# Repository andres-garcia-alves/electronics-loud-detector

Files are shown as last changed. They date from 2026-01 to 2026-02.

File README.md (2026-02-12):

# Loud Detector

A loud detector based on ATtiny85.  
Sensitivity threshold and buzzer volume can be configured through trimmers.  
Schematics diagram + PCB diagram (KiCAD 9) and case 3D model (Blender) are also provided.  

&nbsp;

### Features & Notes:

- Sound detection via peak-to-peak window (robust)
- Sensitivity (threshold) via RV1 ADC
- Volume is 100% analog (RV2 in series with buzzer)
- Buzzer + LED share PB1 (digital ON/OFF)
- Mic power gating via PB0 (high-side PNP typical => logic inverted)
- Power input: 18650 battery

&nbsp;

### List of Materials

- 1 x ATtiny85 IC
- 1 x KY-037 Audio sensor module
- 1 x BJT Transistor BC547
- 1 x BJT Transistor BC557
- 1 x 10k ohms trimmer
- 1 x 500 ohms trimmer
- 2 x LED (yellow + red)
- 1 x Buzzer (pasive)
- 1 x Resistor 470 ohms
- 1 x Resistor 1k ohms
- 1 x Resistor 10k ohms
- 2 x Resistor 2k ohms
- 1 x Resistor 100k ohms
- 1 x Capacitor 100 uF (electrolitic)
- 1 x Capacitor 10 uF
- 1 x Rocker Button (power on/off)
- 1 x MT3608 DC/DC Step-Up Converter Module
- 2 x Bornier connector 2-pins / 2 x JST connector 2-pins
- 2 x Header connector 2-pins
- 1 x 18650 battery
- 1 x 18650 battery holder
- Wires

&nbsp;

### Screenshots

| Breadboard | Assembly |
|---|---|
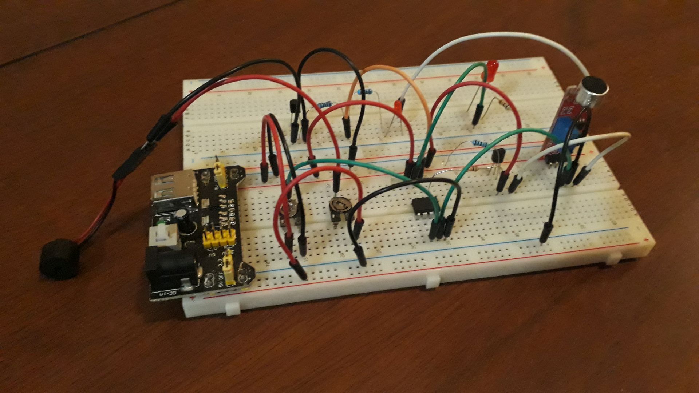
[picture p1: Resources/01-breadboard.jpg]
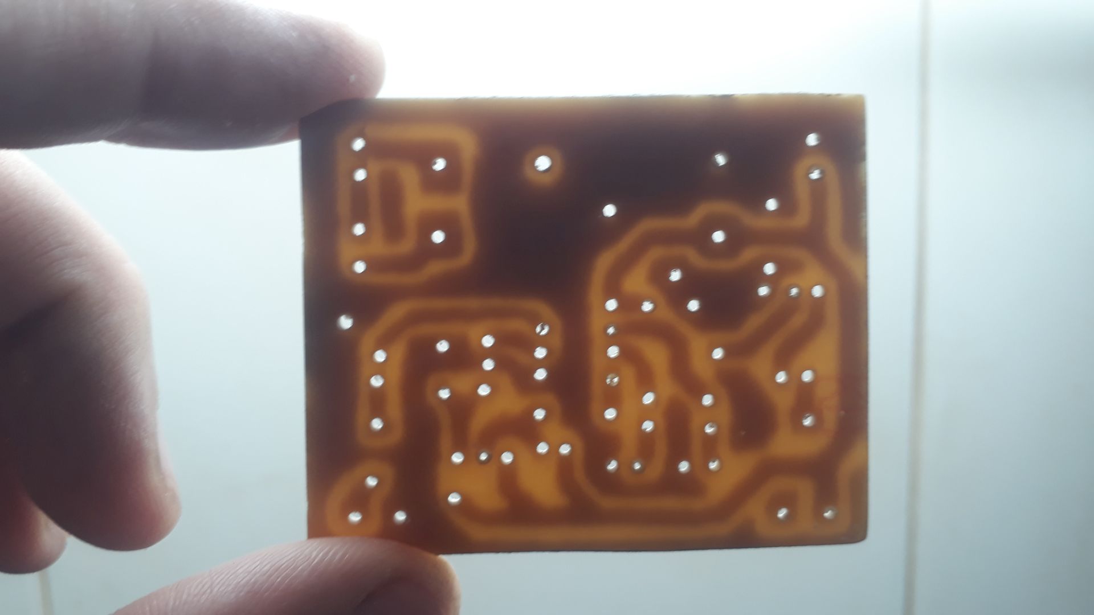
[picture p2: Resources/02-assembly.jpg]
|  |  |

| Schematics Diagram | PCB Layout |
|---|---|
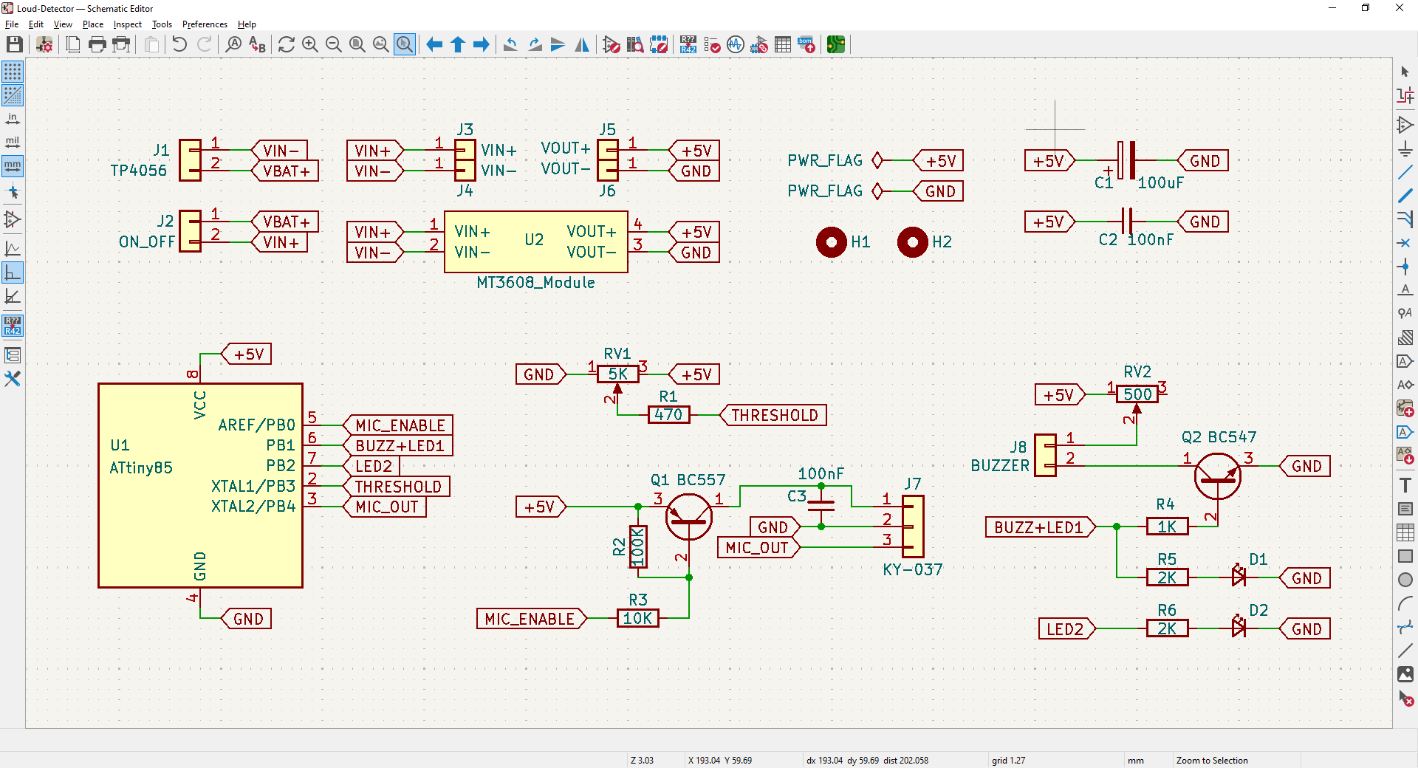
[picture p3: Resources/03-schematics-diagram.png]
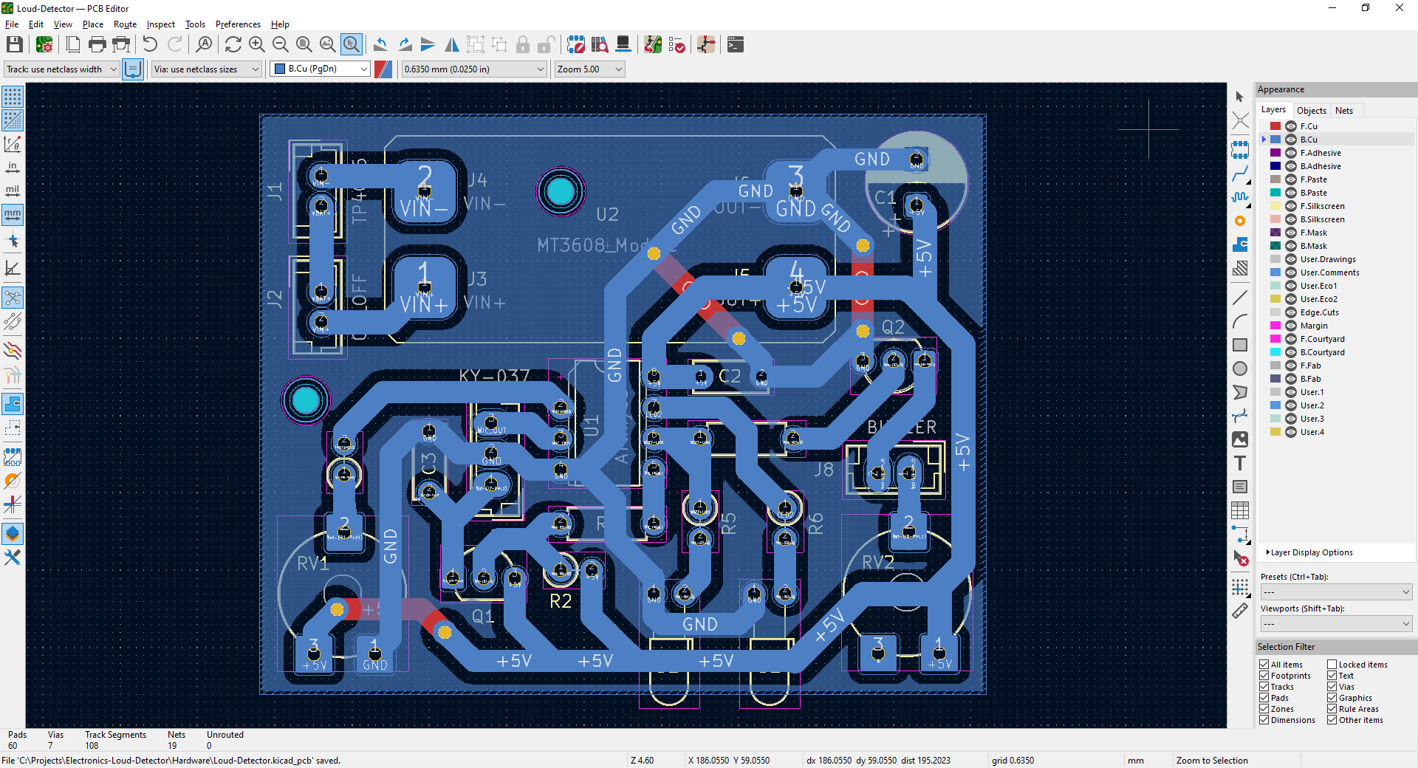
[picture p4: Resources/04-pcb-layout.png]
|  |  |

| PCB Render 3D | PCB Render 3D |
|---|---|
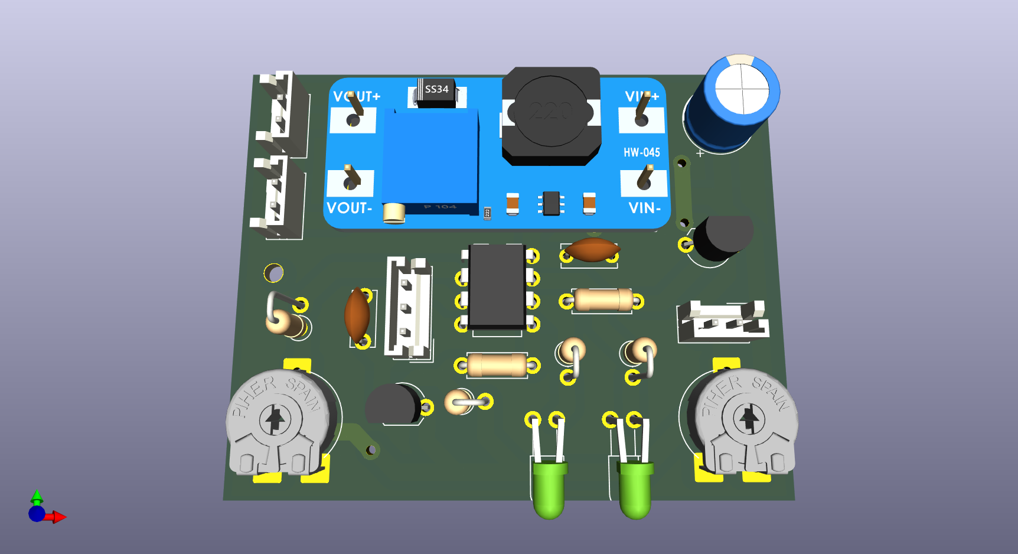
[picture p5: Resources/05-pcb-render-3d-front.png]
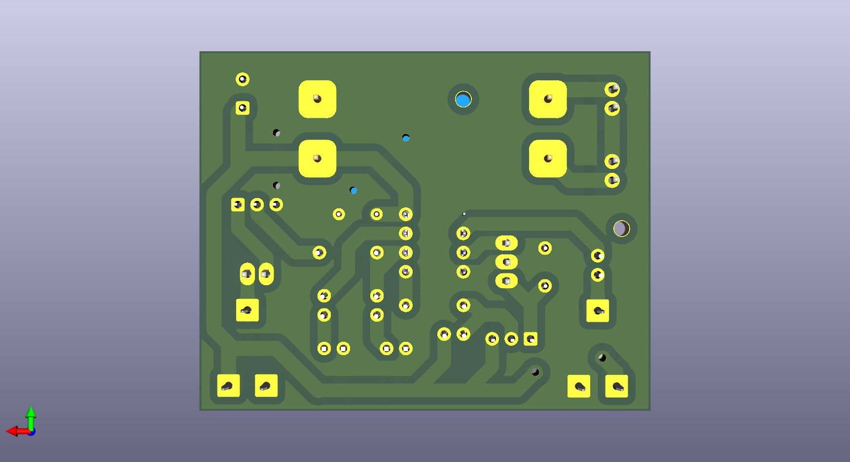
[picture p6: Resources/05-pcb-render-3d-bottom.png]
|  |  |

| Case 3D Model | Project Final |
|---|---|
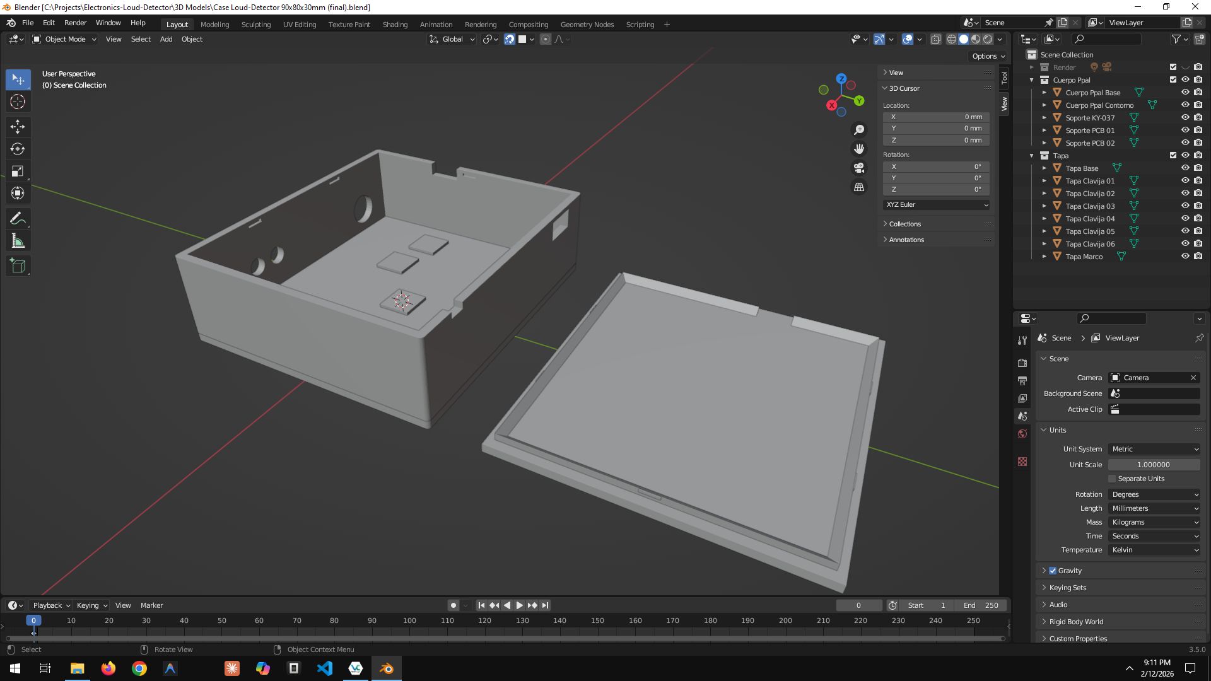
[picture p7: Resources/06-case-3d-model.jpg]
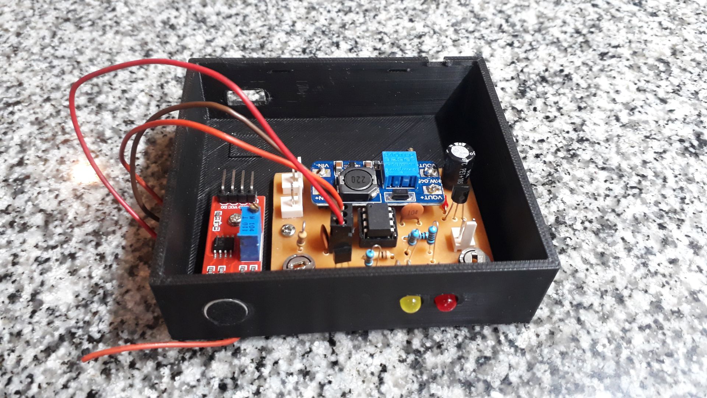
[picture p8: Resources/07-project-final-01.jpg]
|  |  |

| Project Final | Project Final |
|---|---|
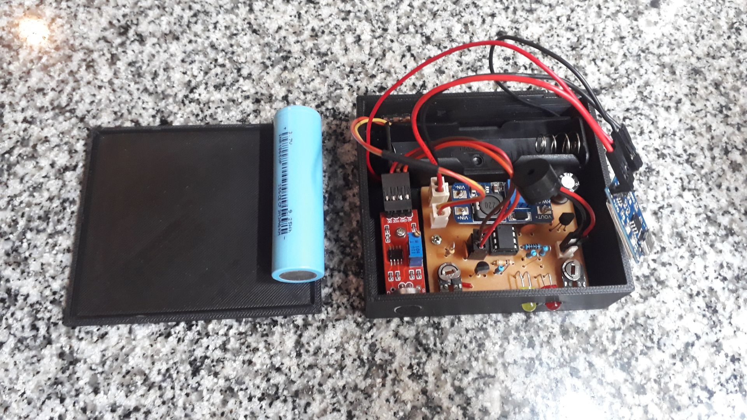
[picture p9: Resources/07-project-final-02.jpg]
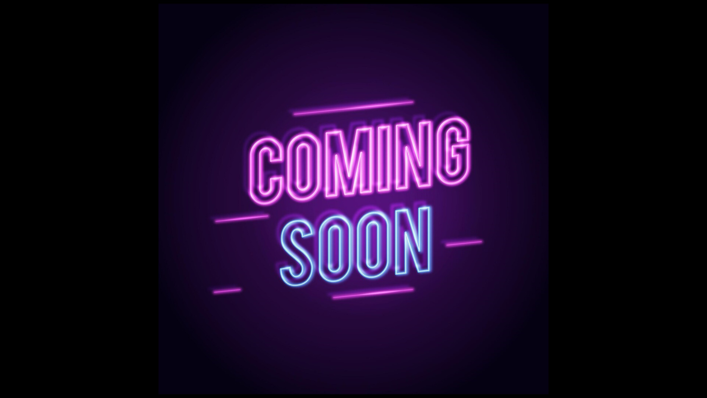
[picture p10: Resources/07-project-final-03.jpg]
|  |  |

See 'Resources' folder for more pictures & videos of the project.

&nbsp;

### Version History

v1.0 (2026.01.24) - Adding schematics, PCB layout and base firmware.  
v1.1 (2026.01.25) - Update firmware: adding 'low-power' feature.  
v1.2 (2026.01.27) - Adding case 3D model.  
v1.3 (2026.01.31) - PCB minor improvements.  
v1.4 (2026.02.02) - Case 3D model minor improvements.  
v1.5 (2026.02.12) - Case 3D model minor improvements, update 'README.md'.  

&nbsp;

This source code is licensed under GPL v3.0  
Please send me your feedback about this project: andres.garcia.alves@gmail.com

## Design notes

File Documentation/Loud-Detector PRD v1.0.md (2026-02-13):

# PRD - Detector de Griterío de bajo consumo con ATtiny85
Versión: 1.0  
Autor: Andrés Garcia Alves

## 1. Objetivo del Producto

Construir un detector autónomo de sonido fuerte basado en ATtiny85 que:
- Detecte eventos de volumen alto
- Active buzzer y LEDs solo cuando corresponda
- Minimize consumo (modo sleep dominante)
- Permanezca encendido semanas o meses
- Incluye interruptor físico ON/OFF entre batería y booster

## 2. Filosofía de Diseño

- "Dormido" el 99% del tiempo
- Sensado periódico ultracorto (2 veces por segundo)
- Periféricos apagado por defecto
- Activación solo cuando hay evento sonoro

## 3. Alcance (MVP)

- Sensor KY-038 analógico
- Sensibilidad de activación configurable con potenciómetro
- Volumen buzzer configurable con potenciómetro
- 2 niveles/umbrales según intensidad detectada
- Buzzer activo ~5/~10 segs si supera uno o ambos umbrales
- 2 LEDs indicadores solo durante evento
- Interruptor físico general

## 4. Plataforma Hardware

### 4.1 Microcontrolador

- ATtiny85 @ 1 MHz interno
- Programación Arduino IDE

### 4.2 Sensado

- KY-038 AO → ADC
- Alimentación controlada por GPIO mediante **corte high-side**

### 4.3 Actuadores

- Buzzer piezo pasivo (via NPN)
- LEDs × 2 (evento medio/fuerte)

### 4.4 Alimentación

- Li-ion 1 o 2 celdas en paralelo (10440/14500/18650)
- TP4056 para carga
- Interruptor entre batería y booster
- DC/DC converter step-up 3.7 → 5 V (MT3608 o similar)

### 4.5 Filtrado

- 100 µF bulk en 5V
- 2 x 100 nF cerámico cerca de VCC ATtiny y sensor KY-037

## 5. Distribución de Pines del ATtiny85

| Función | Nombre MCU | Pin físico | Tipo |
|---|---|---|---|
| Mic ON/OFF | PB0 | 5 | Salida digital |
| BUZZ+LED1 | PB1 | 6 | Salida digital |
| LED 2 | PB2 | 7 | Salida digital |
| Sensibilidad | A3/ADC3 (PB3) | 2 | Entrada analógica |
| Mic OUT | A2/ADC2 (PB4) | 3 | Entrada analógica |

Notas:
- PB5/RESET se mantiene como reset (descartado, porque usarlo requiere quemar fuses)
- El volumen se maneja de forma 100% analógica (RV2)

## 6. Potenciómetros

### 6.1 Umbral sensibilidad (ADC)

Conexión:
5V — pot — GND  
Cursora → ADC  
Firmware compara mic vs pot

### 6.2 Volumen buzzer

5V → pot → buzzer → NPN → GND
Pote 5k–20k lineal
Resistencia mínima a GND 100–330Ω

## 7. Software: Requisitos Funcionales

### Ciclo operativo

1. Dormir Power-down
2. WDT wake cada ~1 s
3. Encender sensor (GPIO + high-side)
4. Esperar 10 ms
5. Leer ADC (32 muestras)
6. Leer pot umbral
7. Evaluar evento
8. Apagar sensor
9. Si evento: LEDs ON + Buzzer ON (~5 s)
10. Dormir

### ADC & filtrado

- 32 muestras
- Descartar primera tras encender sensor
- 1 ms entre lecturas
- ADC clock ≤ 200 kHz
- Promedio ventana

## 8. Gestión Energética

### Estados normales

| Elemento | Estado |
|---|---|
| Sensor | Apagado  |
| LEDs | Apagados |
| Buzzer | Apagado  |
| MCU | Sleep |

### Wake periódico

- WDT cada ~0.5 a ~1 s.

## 9. Consumo y Autonomía

### Consumos típicos

| Componente | Modo | Consumo  |
|---|---|---|
| ATtiny sleep | Power-down | 6–15 µA  |
| KY-038 | Encendido  | 4–6 mA |
| LED | ON | 3–5 mA |
| Buzzer | Evento | 20–40 mA |

### Promedio global esperado

~30–50 µA (sin eventos frecuentes)

### Autonomía estimada

| Batería | Capacidad | Autonomía |
|---|---|---|
| 10440 | 350–600 mAh | 1–3 semanas |
| 14500 | 700–1000 mAh  | 1–2 meses |
| 18650 | 2000–3000 mAh | 2–6 meses |
| 2×18650 | 4000–6000 mAh | 6–12 meses  |

## 10. Validación

- Pruebas con niveles reales (habla / aplausos / música / grito)
- Medición de consumo en reposo y evento
- Ajuste de pot sensibilidad

## 11. Entregables

- Diseño KiCad
- BOM
- Firmware .ino
- Pruebas de autonomía

## 12. Confirmado explícitamente

✔ Corte high-side  
✔ Sleep WDT 1 s  
✔ 2 potenciómetros: umbral + volumen  
✔ 3 LEDs solo en evento  
✔ Autonomía de semanas/meses  
✔ Interruptor ON/OFF físico  
✔ Mantener KY-038  
✔ Sin pantallas ni extras  

## 13. Para Versión 1.1 (solo Firmware)

- Aumentar sensibilidad de activación con:
  - Se puede "hilar fino" en el firmware ajustando THR_MIN_P2P / THR_MAX_P2P

  - Respuesta ChatGPT
    - aumentar ventana de muestreo (40 → 80 ms)
    - RMS o energía acumulada
    - rectificación + promedio
    - threshold dinámico relativo al ruido base
    - Todo eso: mejora sensibilidad, reduce falsos negativos, sin aumentar consumo

## 14. Para Versión 2.0 (Hardware)

- Aumentar autonomía con:
  - Mantener lógica de 2 umbrales de audio (5-10 segundos del buzzer), pero eliminar el LED2
  - Utilizar el pin liberado para controlar la alimentación del umbral de sensibilidad (RV1)
  - Actualmente RV1 (10K) es un consumo **permanente** de 500uA
  - Desactivar el BOD del ATtiny85
  - Desactivar Timer1 del ATtiny85 (revisar que no afecte al Buzzer)

## 15. Fuera de Alcance

- Pantallas
- Comunicación
- Registro de datos
- Sensores alternativos

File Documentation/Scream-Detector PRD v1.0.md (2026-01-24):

# PRD — Detector de Gritos de Bajo Consumo con ATtiny85
Versión: 1.0  
Autor: Andrés Garcia Alves

## 1. Objetivo del Producto
Construir un detector autónomo de sonido fuerte basado en ATtiny85 que:
- Detecte eventos de volumen alto
- Active buzzer y LEDs solo cuando corresponda
- Minimize consumo (modo sleep dominante)
- Permanezca encendido semanas o meses
- Incluye interruptor físico ON/OFF entre batería y booster

## 2. Filosofía de Diseño
- "Dormido" el 99% del tiempo
- Sensado periódico ultracorto (1× por segundo)
- Todo periférico apagado por defecto
- Activación solo cuando hay evento sonoro

## 3. Alcance (MVP)
- Sensor KY-038 analógico
- Umbral configurable con potenciómetro
- Volumen buzzer configurable con potenciómetro
- 3 LEDs indicadores solo durante evento
- Buzzer activo ~5 s si supera umbral
- Sin comunicaciones
- Interruptor físico general

## 4. Plataforma Hardware

### 4.1 Microcontrolador
- ATtiny85 @ 1 MHz interno
- Programación Arduino IDE

### 4.2 Sensado
- KY-038 AO → ADC
- Alimentación controlada por GPIO mediante **corte high-side**

### 4.3 Actuadores
- LEDs × 3 (evento leve/medio/fuerte)
- Buzzer piezo activo (via NPN)

### 4.4 Alimentación
- Li-ion 1 o 2 celdas en paralelo (10440/14500/18650)
- TP4056 para carga
- Interruptor entre batería y booster
- Step-up 3.7 → 5 V (MT3608 o similar)

### 4.5 Filtrado
- 100 µF bulk en 5V
- 100 nF cerámico cerca de VCC ATtiny

## 5. Distribución de Pines del ATtiny85

| Función | Pin físico | Nombre MCU | Tipo |
|---|---|---|---|
Mic audio | 7 | PB2 / ADC1 | Entrada analógica |
Umbral pot | 3 o 2* | PB4 / ADC2 | Entrada analógica |
Corte alimentación mic | 6 | PB1 | Salida digital |
Buzzer (NPN) | 5 | PB0 | Salida digital |
LED 1 | 2 o 3* | PB3 | Salida digital |
LED 2 | 2/3/4* | PB3/PB4 | Salida digital |
LED 3 | 0/1/5* | PB0/PB? | Salida digital |

*PB5/RESET se mantiene como reset (no se usa).

## 6. Potenciómetros

### 6.1 Umbral sensibilidad (ADC)
Conexión:
5V — pot — GND  
Cursora → ADC  
Firmware compara mic vs pot

### 6.2 Volumen buzzer
5V → pot → buzzer → NPN → GND
Pote 5k–20k lineal
Resistencia mínima a GND 100–330Ω

## 7. Software: Requisitos Funcionales

### Ciclo operativo
1. Dormir Power-down
2. WDT wake cada ~1 s
3. Encender sensor (GPIO + high-side)
4. Esperar 10 ms
5. Leer ADC (32 muestras)
6. Leer pot umbral
7. Evaluar evento
8. Apagar sensor
9. Si evento:
   - LEDs ON (~5 s)
   - Buzzer ON (~5 s)
10. Dormir

### ADC & filtrado
- 32 muestras
- Descartar primera tras encender sensor
- 1 ms entre lecturas
- ADC clock ≤ 200 kHz
- Promedio ventana

## 8. Gestión Energética

### Estados normales
| Elemento | Estado |
|---|---|
Sensor | Apagado |
LEDs | Apagados |
Buzzer | Apagado |
MCU | Sleep |

### Wake periódico
- WDT cada ~1 s

## 9. Consumo y Autonomía

### Consumos típicos
| Componente | Modo | Consumo |
|---|---|---|
ATtiny sleep | Power-down | 6–15 µA |
KY-038 | Encendido | 4–6 mA |
LED | ON | 3–5 mA |
Buzzer | Evento | 20–40 mA |

### Promedio global típico
~30–50 µA (sin eventos frecuentes)

### Autonomía estimada
| Batería | Capacidad | Autonomía |
|---|---|---|
10440 | 350–600 mAh | 1–3 semanas |
14500 | 700–1000 mAh | 1–2 meses |
18650 | 2000–3000 mAh | 2–6 meses |
2×18650 | 4000–6000 mAh | 6–12 meses |

## 10. Validación
- Pruebas con niveles reales (habla / aplausos / música / grito)
- Medición de consumo en reposo y evento
- Ajuste de pot sensibilidad

## 11. Entregables
- Diseño KiCad
- BOM
- Firmware .ino
- Pruebas de autonomía

## 12. Confirmado explícitamente
✔ Corte high-side  
✔ Sleep WDT 1 s  
✔ 2 potenciómetros: umbral + volumen  
✔ 3 LEDs solo en evento  
✔ Autonomía de semanas/meses  
✔ Interruptor ON/OFF físico  
✔ Mantener KY-038  
✔ Sin pantallas ni extras  

## 13. Fuera de Alcance
- Pantallas
- Comunicación
- Registro de datos
- Sensores alternativos

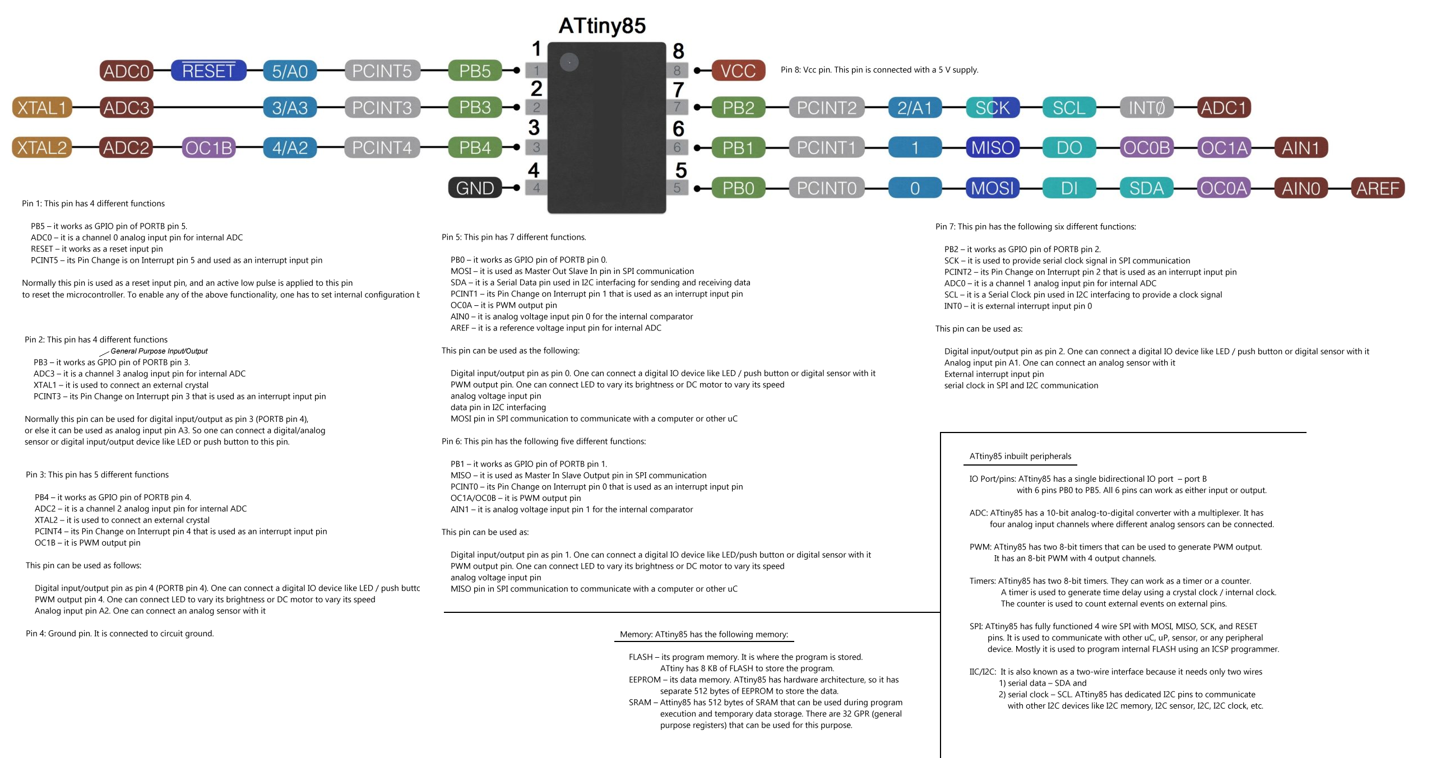
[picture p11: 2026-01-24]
Datasheets/Pinout MCU ATiny85.png

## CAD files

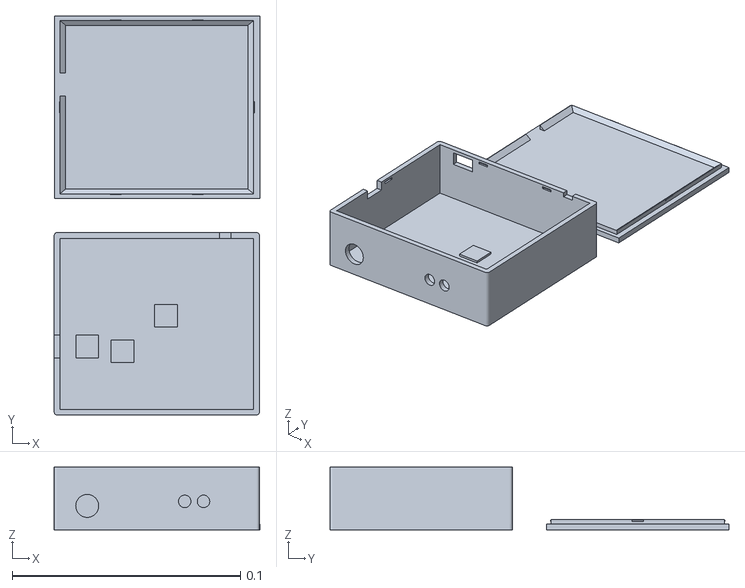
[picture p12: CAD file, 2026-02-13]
3D Models/Case Loud-Detector 90x80x30mm (final).stl
0.0902 x 0.175 x 0.0275

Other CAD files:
3D Models/Case Loud-Detector 90x80x30mm (final).blend
3D Models/Case Loud-Detector 90x80x30mm (without holes).blend

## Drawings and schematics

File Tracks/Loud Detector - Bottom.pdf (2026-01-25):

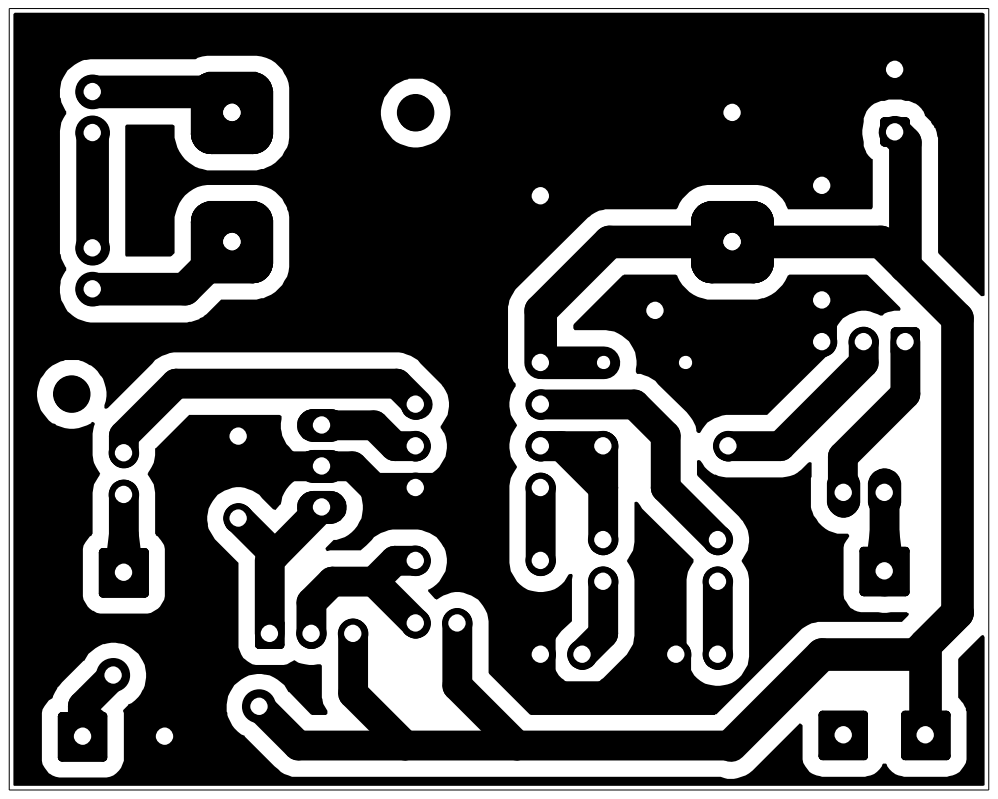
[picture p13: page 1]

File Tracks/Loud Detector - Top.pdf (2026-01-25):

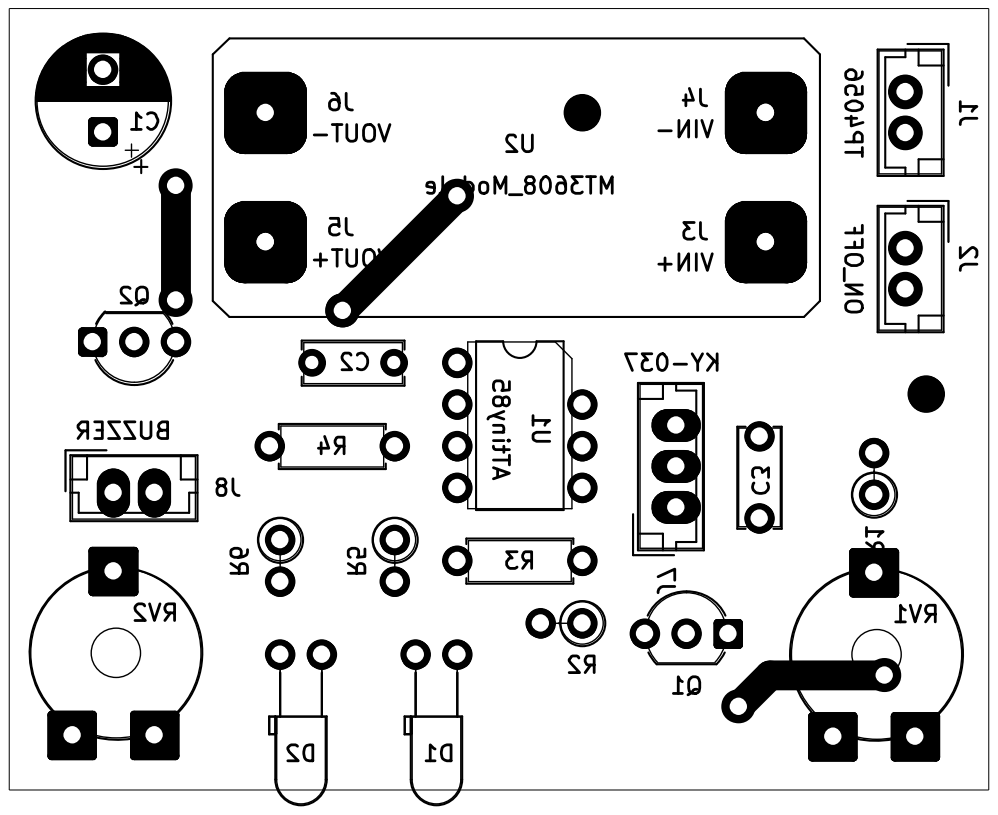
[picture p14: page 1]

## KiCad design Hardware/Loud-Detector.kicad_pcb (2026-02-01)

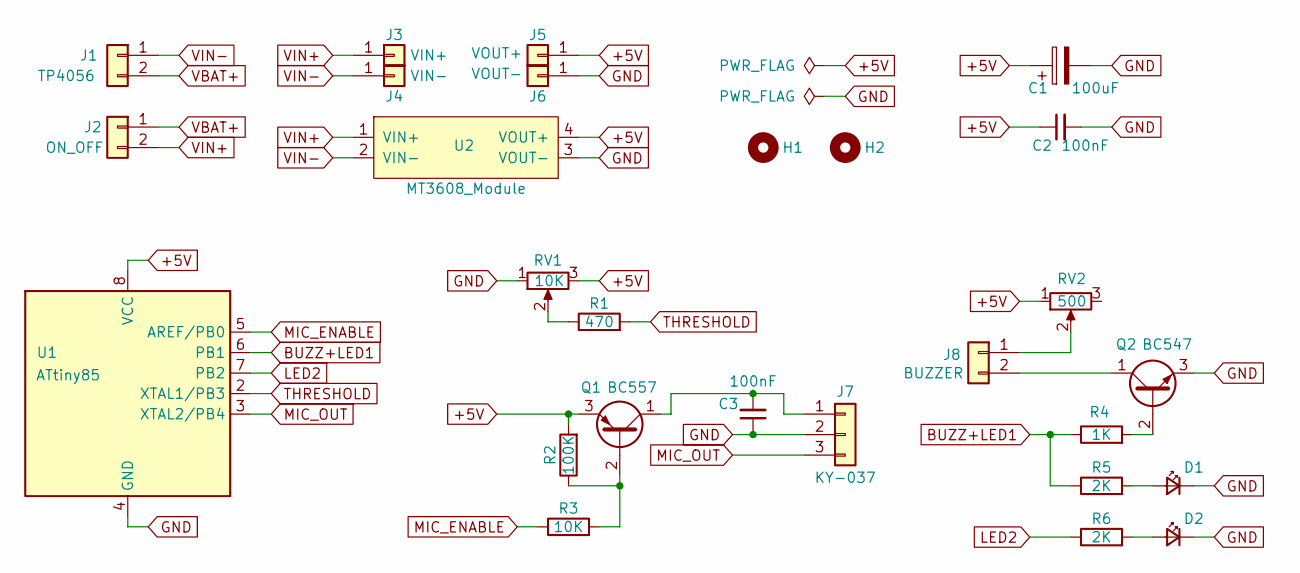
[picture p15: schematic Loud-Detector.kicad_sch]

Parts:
C1: 100uF; CP_Radial_D8.0mm_P3.80mm
C2, C3: 100nF; C_Disc_D6.0mm_W2.5mm_P5.00mm; Voltage 1kV; Tolerance 100%
D1, D2: LED; LED_D3.0mm_Horizontal_O3.81mm_Z6.0mm
H1, H2: MountingHole; MountingHole_2.2mm_M2_ISO7380
J1: TP4056; JST_EH_B2B-EH-A_1x02_P2.50mm_Vertical
J2: ON_OFF; JST_EH_B2B-EH-A_1x02_P2.50mm_Vertical
J3: VIN+; PinHeader_1x01_P2.54mm_Vertical
J4: VIN-; PinHeader_1x01_P2.54mm_Vertical
J5: VOUT+; PinHeader_1x01_P2.54mm_Vertical
J6: VOUT-; PinHeader_1x01_P2.54mm_Vertical
J7: KY-037; JST_EH_B3B-EH-A_1x03_P2.50mm_Vertical
J8: BUZZER; JST_EH_B2B-EH-A_1x02_P2.50mm_Vertical
Q1: BC557; TO-92_Inline_Wide
Q2: BC547; TO-92_Inline_Wide
R1: 470; R_Axial_DIN0207_L6.3mm_D2.5mm_P2.54mm_Vertical
R2: 100K; R_Axial_DIN0207_L6.3mm_D2.5mm_P2.54mm_Vertical
R3: 10K; R_Axial_DIN0207_L6.3mm_D2.5mm_P7.62mm_Horizontal
R4: 1K; R_Axial_DIN0207_L6.3mm_D2.5mm_P7.62mm_Horizontal
R5, R6: 2K; R_Axial_DIN0207_L6.3mm_D2.5mm_P2.54mm_Vertical
RV1: 10K; Trimmer_Piher_PT10-V10_Vertical
RV2: 500; Trimmer_Piher_PT10-V10_Vertical
U1: ATtiny85; DIP-8_W7.62mm
U2: MT3608_Module; DC_Boost_Converter_MT3608_Module

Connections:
+5V: C1.1, C2.1, J5.1, Q1.3 (E), R2.2, RV1.3, RV2.1, U1.8 (VCC), U2.4 (VOUT+)
BUZZ+LED1: R4.1, R5.1, U1.6 (PB1)
GND: C1.2, C2.2, C3.1, D1.1 (K), D2.1 (K), J6.1, J7.2, Q2.3 (E), RV1.1, U1.4 (GND), U2.3 (VOUT-)
LED2: R6.1, U1.7 (PB2)
MIC_ENABLE: R3.1, U1.5 (AREF/PB0)
MIC_OUT: J7.3, U1.3 (XTAL2/PB4)
unnamed: D1.2 (A), R5.2
unnamed: D2.2 (A), R6.2
unnamed: C3.2, J7.1, Q1.1 (C)
unnamed: J8.1, RV2.2
unnamed: J8.2, Q2.1 (C)
unnamed: Q1.2 (B), R2.1, R3.2
unnamed: Q2.2 (B), R4.2
unnamed: R1.1, RV1.2
THRESHOLD: R1.2, U1.2 (XTAL1/PB3)
VBAT+: J1.2, J2.1
VIN+: J2.2, J3.1, U2.1 (VIN+)
VIN-: J1.1, J4.1, U2.2 (VIN-)

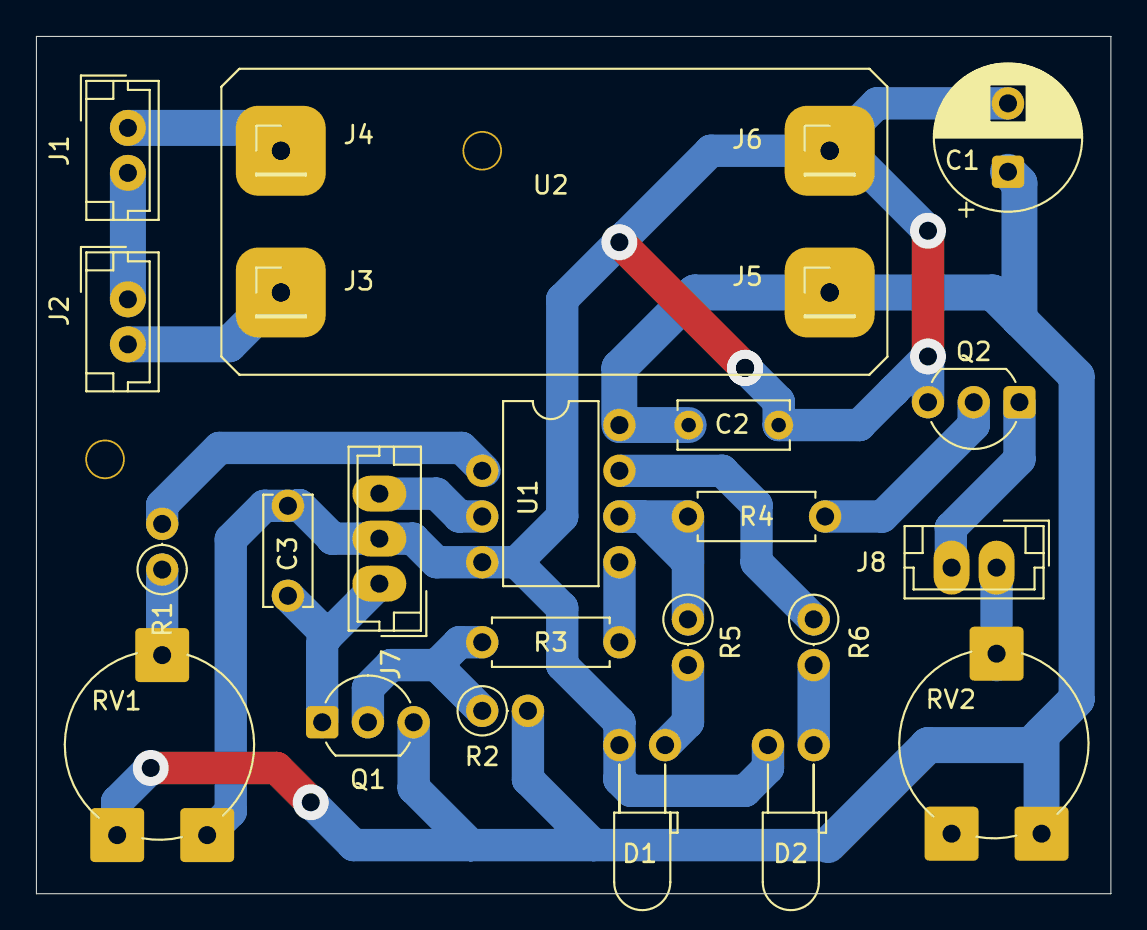
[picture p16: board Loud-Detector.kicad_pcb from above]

Board: 2 copper layers, 59.7 x 47.6 mm, 27 parts (0 on the bottom side), 18 nets.

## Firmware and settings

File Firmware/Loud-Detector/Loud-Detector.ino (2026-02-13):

/*
  Loud Detector - Firmware v1.0
  Target: ATtiny85 @ 1 MHz
  Sensor: KY-037/KY-038 (analog out)

  Features:
  - Sound detection via energy (mean abosolute deviation)
  - Sound detection via peak-to-peak window (OBSOLETE)
  - Sensitivity (threshold) via RV1 ADC
  - 2 noise levels (LED2 indicates LEVEL2)
  - Volume is 100% analog (RV2 in series with buzzer)
  - Buzzer + LED share PB1 (digital ON/OFF)
  - Buzzer via tone()
  - Mic power gating via PB0 (high-side PNP typical => logic inverted)
  - Sleep mode using Watchdog (~500ms wakeups)
*/

#include "hardware.h"
#include "low-power.h"
#include "control-logic.h"


void setup()
{
  hardwareInit();
  powerInit();
  delay(200);
}

void loop()
{
  if (isBuzzing())
  {
    checkBuzzStop();
    checkLoudEnvironment();
    delay(30);  // fast polling while alarm is active
  }
  else
  {
    checkLoudEnvironment();
    sleep();    // ~500ms low power idle (WDT wake-up)
  }
}

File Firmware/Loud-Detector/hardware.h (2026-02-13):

#pragma once

// pin mapping (ATtiny85)
#define PIN_MIC_ENABLE    PB0     // PB0 -> Controls Q1 high-side
#define PIN_BUZZ_LED      PB1     // PB1 -> Q2 base + LED1
#define PIN_LED2          PB2     // PB2 -> LED2

#define PIN_MIC_ADC       A2      // PB4 (ADC2) -> KY-038 sensor (pin AO)
#define PIN_THR_ADC       A3      // PB3 (ADC3) -> RV1 sensitivity control

// inverse logic (Q1: BC557)
#define MIC_ON            LOW
#define MIC_OFF           HIGH

// audio sensor parameters (KY-037/KY-038)
#define SENSOR_WARMUP_MS  20UL    // 20 ms
#define SENSOR_WINDOW_MS  40UL    // 40 ms

// threshold mapping (RV1 -> peak-to-peak threshold)
//#define THR_MIN_P2P       8       // very sensitive
//#define THR_MAX_P2P       220     // very strict
#define THR_MIN_ENERGY    2//5
#define THR_MAX_ENERGY    30//60

// variables + enums
enum LoudLevel {LEVEL1, LEVEL2};

// funtions declaration + inline functions
void inline micPowerOn()  { digitalWrite(PIN_MIC_ENABLE, MIC_ON); delay(SENSOR_WARMUP_MS); }
void inline micPowerOff() { digitalWrite(PIN_MIC_ENABLE, MIC_OFF); }


// module initialization
void hardwareInit()
{
  pinMode(PIN_MIC_ENABLE, OUTPUT);
  pinMode(PIN_MIC_ADC, INPUT);
  pinMode(PIN_THR_ADC, INPUT);
  pinMode(PIN_BUZZ_LED, OUTPUT);
  pinMode(PIN_LED2, OUTPUT);

  micPowerOff();
  digitalWrite(PIN_BUZZ_LED, LOW);
  digitalWrite(PIN_LED2, LOW);
}


void buzzStart(LoudLevel loudLevel)
{
  // digital ON (volume handled by analog trimmer RV2)
  tone(PIN_BUZZ_LED, 2000);   // 2 Khz

  if (loudLevel == LEVEL2) { digitalWrite(PIN_LED2, HIGH); }
}

void buzzStop()
{
  noTone(PIN_BUZZ_LED);
  digitalWrite(PIN_LED2, LOW);
}

int micMeasureEnergy()
{
  unsigned long start = millis();
  long sum = 0;
  int samples = 0;

  // Primero estimamos el nivel medio
  long mean = 0;
  int count = 0;

  while (millis() - start < SENSOR_WINDOW_MS)
  {
    int value = analogRead(PIN_MIC_ADC);
    mean += value;
    count++;
  }

  mean /= count;

  // Segunda pasada: energía absoluta
  start = millis();
  while (millis() - start < SENSOR_WINDOW_MS)
  {
    int value = analogRead(PIN_MIC_ADC);
    sum += abs(value - mean);
    samples++;
  }

  return sum / samples;  // energía promedio
}

/*int micMeasurePeakToPeak()
{
  int minRaw = 1023;
  int maxRaw = 0;
  unsigned long start = millis();

  while (millis() - start < SENSOR_WINDOW_MS)
  {
    int value = analogRead(PIN_MIC_ADC);

    if (value < minRaw) { minRaw = value; }
    if (value > maxRaw) { maxRaw = value; }
  }

  return maxRaw - minRaw;
}*/

int adcThresholdEnergy()
{
  int thresholdRaw = analogRead(PIN_THR_ADC);   // 0..1023
  int threshold = map(thresholdRaw, 0, 1023, THR_MIN_ENERGY, THR_MAX_ENERGY);

  if (threshold < THR_MIN_ENERGY) { threshold = THR_MIN_ENERGY; }
  if (threshold > THR_MAX_ENERGY) { threshold = THR_MAX_ENERGY; }

  return threshold;
}

/*int adcThresholdPeakToPeak()
{
  int thresholdRaw = analogRead(PIN_THR_ADC);   // 0..1023
  int threshold = map(thresholdRaw, 0, 1023, THR_MIN_P2P, THR_MAX_P2P);

  // Safety clamp
  if (threshold < THR_MIN_P2P) { threshold = THR_MIN_P2P; }
  if (threshold > THR_MAX_P2P) { threshold = THR_MAX_P2P; }

  return threshold;
}*/

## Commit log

2026-01-24 Adding schematics, PCB layout and base firmware
    [Loud-Detector.kicad_pcb, Loud-Detector.kicad_sch]
2026-01-25 Update firmware: adding 'low-power' feature
    [Loud-Detector.kicad_sch]
2026-01-27 Adding case 3D model
    [Case 86x76x27mm (without holes).blend]
2026-01-31 PCB minor improvements
    [Loud-Detector.kicad_pcb, Loud-Detector.kicad_sch]
2026-02-02 3D model minor improvements
    [Case Loud-Detector 90x80x27mm (final).blend, Case Loud-Detector 90x80x27mm (final).stl, Case Loud-Detector 90x80x27mm (without holes).blend]
2026-02-11 Case 3D model minor improvements
    [Case Loud-Detector 90x80x27mm (final).blend, Case Loud-Detector 90x80x27mm (final).stl, Case Loud-Detector 90x80x27mm (without holes).blend]
